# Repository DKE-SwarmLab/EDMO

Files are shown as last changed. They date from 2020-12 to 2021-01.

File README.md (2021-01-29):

# EDMO
Repository for EDucational MOdular Robots (EDMO)

EDMO is a custom-made EDucational MOdular robotic platform developed for robotics education at Maastricht University. The EDMO platform is designed as a versatile, modular robotic platform that allows students to construct and explore a variety of robotic morphologies including snake, biped, and quadruped configurations.

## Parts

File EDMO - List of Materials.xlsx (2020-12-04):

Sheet: EDMO BOX
List of Materials - EDMO BOX For EDMO Version 1.0 and 1.1
Table 1: Material costs (upper limits) for one EDMO box and components
Component | Amount | Costs[€]*
EDMO 1.0 robot module
3D-printed body parts and fasteners | 1 | 4.50
TurnigyTM TGY-50090M servo motor | 1 | 5.50
EDMO 1.1 robot module
3D-printed body parts and fasteners | 1 | 4.50
TrackStarTM TS-411MG servo motor | 1 | 15.60
EDMO DC motor module
3D-printed body parts | 1 | 3.00
RS PRO 6V brushed DC geared motor | 1 | 15.20
Amphenol Piher N15TS-103A3030 rotary encoder | 1 | 2.40
Electronics
Adafruit Feather M0 Proto board | 1 | 18.00
Adafruit Feather servo wing | 1 | 9.00
L298N DC motor driver board | 1 | 5.00
5V DC - 2A Raspberry Pi power converter | 1 | 6.80
Breadboard (53x82)mm | 1 | 5.00
10 kΩ metal film resistor (for LED) | 2 | 0.60
68 Ω metal film resistor | 3 | 1.20
RG-LED | 1 | 0.40
Proto cables male-male | 5 | 3.60
Proto cables female-male | 3 | 3.60
2-Position Switch | 1 | 0.90
USB-A to µUSB Cable | 1 | 4.90
Servo extension cables (60cm)(optional) | 3 | 3.70
Various
Plastic box/organizer | 1 | 20.00
Screwdriver, Flat, 2.5mm Tip | 1 | 4.00
Total costs of box with 2x EDMO 1.0 robot modules |  | <125
Total costs of box with 2x EDMO 1.1 robot modules |  | <145
*Costs per smallest available purchasing or production unit

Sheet: EDMO 1.0
List of Components - EDMO 1.0 -
Table 2: Parts of one EDMO robot version 1.0
Component | Amount
EDMO 1.0 body (PLA) | 1
EDMO 1.0 cover (PLA) | 1
EDMO 1.0 arm (PLA) | 1
TurnigyTM TGY-50090M servo motor | 1
Screw DIN 912 - M3x20mm | 1
Screw DIN 912 - M2x20mm | 1
Nut DIN 985 - M3 | 3
Washer DIN 125 - 3.2x7 | 4
Spirol threaded inserts M2x4mm | 2

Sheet: EDMO 1.1
List of Components - EDMO 1.1 -
Table 3: Parts of one EDMO robot version 1.1
Component | Amount
EDMO 1.1 body (PLA) | 1
EDMO 1.1 cover (PLA) | 1
EDMO 1.1 arm (PLA) | 1
TrackStarTM TS-411MG servo motor | 1
Screw DIN 912 - M3x16mm | 1
Screw DIN 912 - M2x20mm | 4
Nut DIN 985 - M3 | 6
Nut DIN 934 - M3 | 1
Washer DIN 125 - 3.2x7 | 2

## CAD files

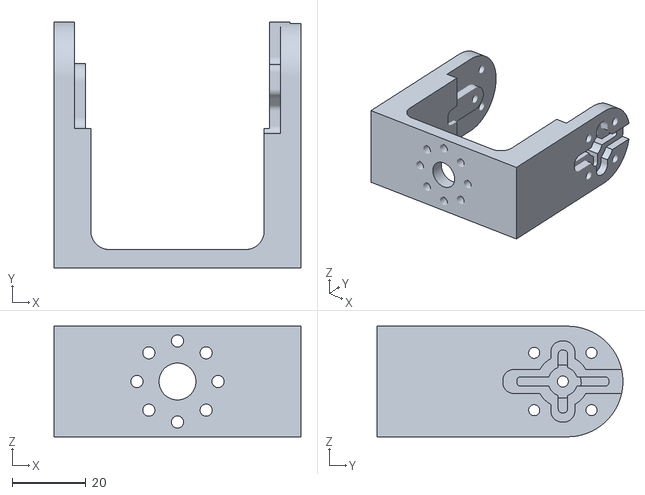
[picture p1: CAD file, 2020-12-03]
EDMO_V1-0/EDMOV1-0 STL/EDMO1-0_Arm.stl
67.0 x 66.7 x 30.0

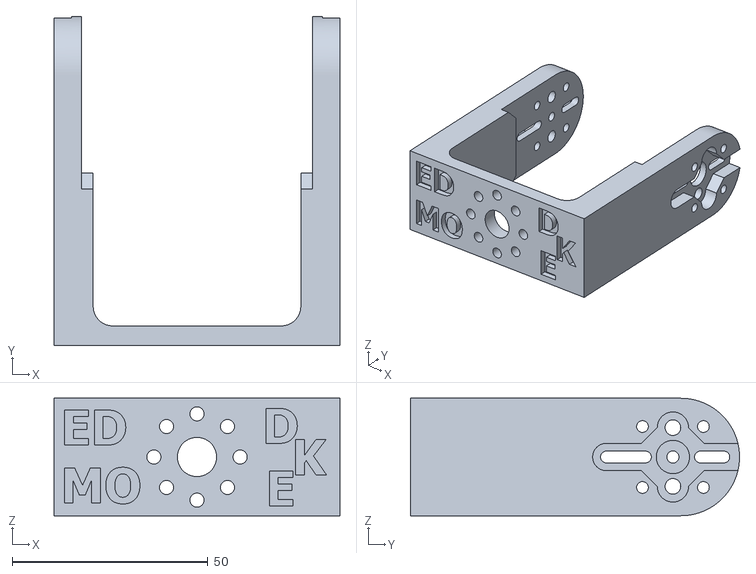
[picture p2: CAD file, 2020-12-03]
EDMO_V1-1/EDMO V1-1 STL/EDMO1-1_Arm.stl
73.0 x 84.0 x 30.0

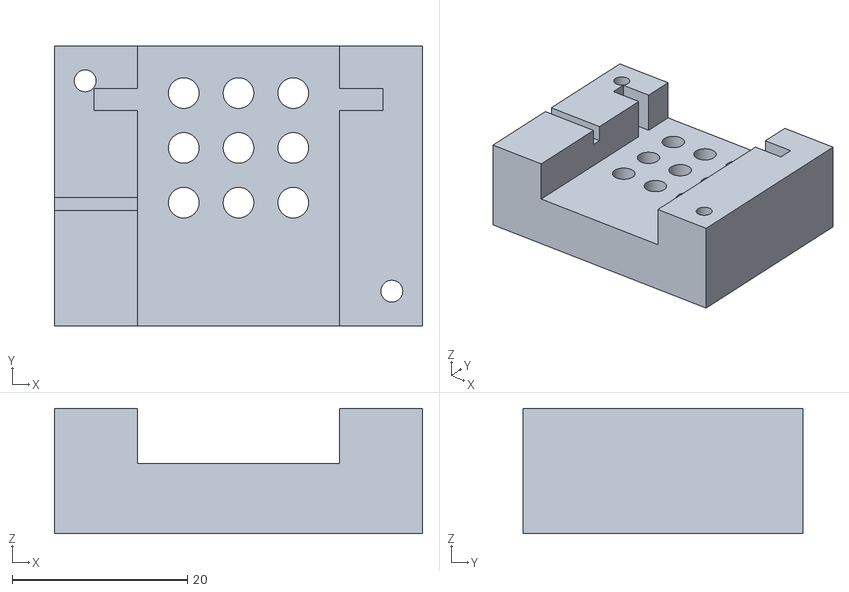
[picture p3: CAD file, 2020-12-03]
EDMO_V1-0/EDMOV1-0 STL/EDMO1-0_Cover.stl
42.0 x 32.0 x 14.3

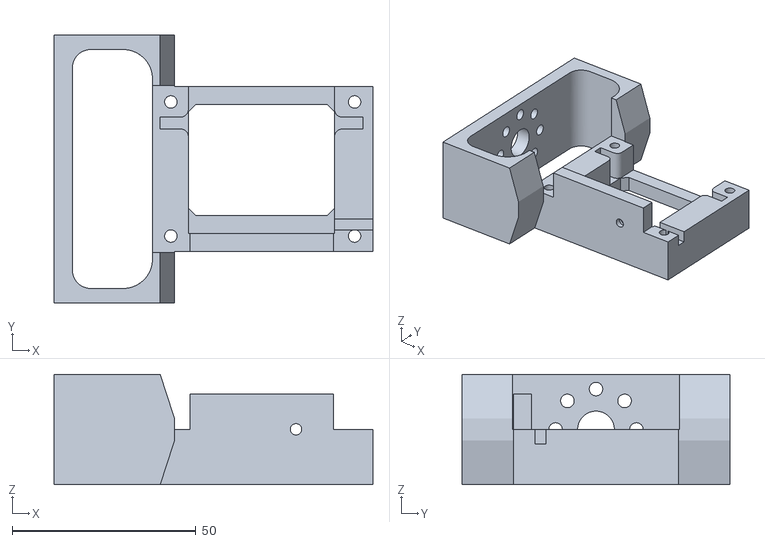
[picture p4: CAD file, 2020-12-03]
EDMO_V1-1/EDMO V1-1 STL/EDMO1-1_Body.stl
86.8 x 73.0 x 30.0

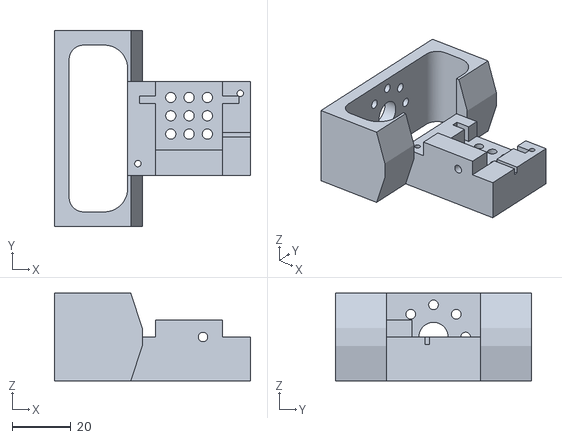
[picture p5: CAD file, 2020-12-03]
EDMO_V1-0/EDMOV1-0 STL/EDMO1-0_Body.stl
67.0 x 67.0 x 30.0

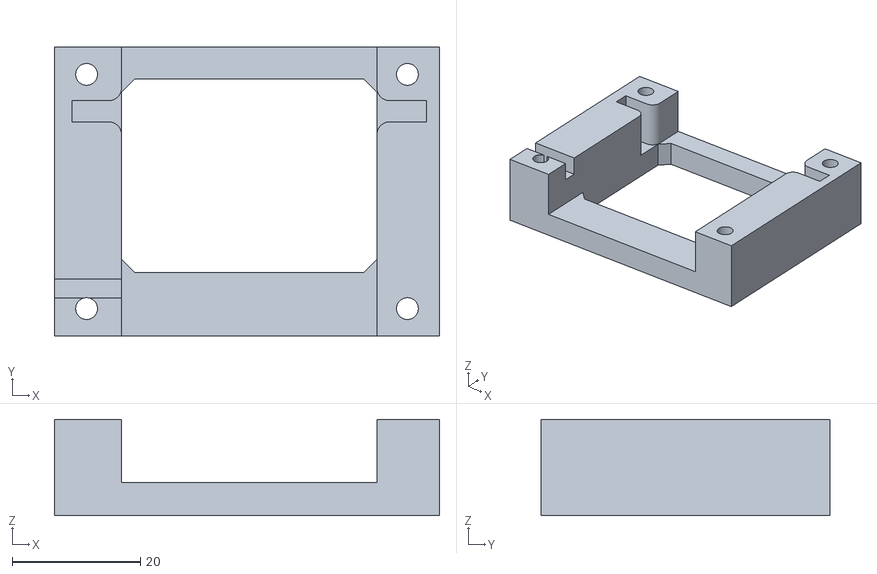
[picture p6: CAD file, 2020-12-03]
EDMO_V1-1/EDMO V1-1 STL/EDMO1-1_Cover.stl
60.0 x 45.0 x 15.0

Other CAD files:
EDMO_V1-0/EDMOV1-0 Inventor/EDMO_Module_TGY_50090M.iam
EDMO_V1-0/EDMOV1-0 Inventor/Workspace/DIN 125 - A 3,2.ipt
EDMO_V1-0/EDMOV1-0 Inventor/Workspace/DIN 912 - M2 x 0,4 x 20 x 19.ipt
EDMO_V1-0/EDMOV1-0 Inventor/Workspace/DIN 912 - M3 x 0,5 x 20 x 18,75.ipt
EDMO_V1-0/EDMOV1-0 Inventor/Workspace/DIN 985 - M3.ipt
EDMO_V1-0/EDMOV1-0 Inventor/Workspace/EDMO1-0_Arm.ipt
EDMO_V1-0/EDMOV1-0 Inventor/Workspace/EDMO1-0_Body.ipt
EDMO_V1-0/EDMOV1-0 Inventor/Workspace/EDMO1-0_Cover.ipt
EDMO_V1-0/EDMOV1-0 Inventor/Workspace/Servo_Horn_Cross_TGY.ipt
EDMO_V1-0/EDMOV1-0 Inventor/Workspace/Turnigy TGY-50090M Analog Servo.ipt
EDMO_V1-0/EDMOV1-0 Inventor/Workspace/spirol_pn_151048.ipt
EDMO_V1-1/EDMOV1-1 Inventor/EDMO1-1_Arm.ipt
EDMO_V1-1/EDMOV1-1 Inventor/EDMO1-1_Body.ipt
EDMO_V1-1/EDMOV1-1 Inventor/EDMO1-1_Cover.ipt
EDMO_V1-1/EDMOV1-1 Inventor/EDMO_TrackStar_TS_411MG.iam
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

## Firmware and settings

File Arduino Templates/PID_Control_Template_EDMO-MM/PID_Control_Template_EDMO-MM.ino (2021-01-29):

//EDMO-Motor Module - PID Control Template
//Author: DKE-SwarmLab
//This script contains a template for the implementation of a PID controller with the EDMO-Motor Module and the L298N DC motor driver board.
//The template provides a framework for the implementation of the PID controller and the operation of the DC motor driver board L298N.
//Furthermore it provides a function to read the PID-gains kp, ki, and kd via the serial monitor. Those need to be entered in the format <kp-value>,<ki-value>,<kd-value>

// *********************************************************************************************************************** //
// Variables                                                                                                               //
// *********************************************************************************************************************** //

//pin definition
#define ENA 9 //Arduino pin connected to the enable pin of the motor driver (for setting the motor speed via PWM)
#define IN1 21 //Arduino pin connected to the In1-pin of the DC motor driver board L298N(for setting the motor direction)
#define IN2 20 //Arduino pin connected to the In2-pin of the DC motor driver board L298N(for setting the motor direction)
#define SENSOR_PIN A0 //Analog input pin of the rotary encoder

// ******** <TODO> **********************
// ******** define interval between recomputing error and adjusting feedback (in milliseconds) ********************** 
const int INTERVAL = 0; 
unsigned long previousTime = 0;

int motorSpeed = 0; // speed of the motor, values between 0 and 255
int target = 512; // position (as read by potentiometer) to move the motor to, default value 512

// ******** <TODO> **********************
// ******** define the different gains **********************
float kp = 0.0; // proportional gain
float ki = 0.0; // integral gain
float kd = 0.0; // derivative gain

int pos = 0; // current position for plotting
//serial communication variables
float PID_values[4];
byte i = 0;
char record[100];
char recvchar;
byte indx = 0;

// setup code, setting pin modes and initialising the serial connection
void setup() 
{
    Serial.begin(115200);

    pinMode(ENA, OUTPUT);
    pinMode(IN1, OUTPUT);
    pinMode(IN2, OUTPUT);    
    pinMode(SENSOR_PIN, INPUT);   
}

void loop() 
{
        //  ******** <TODO> **********************
        //  ******** implement your code  here **********************

        //print actual motor position and target value to serial-monitor/plotter
        Serial.print(pos);
        Serial.print(" ");   
        Serial.println(target);
    
}

// method to set direction and speed of the motor
void setMovement(int dir, int speed1) 
{
        //  ******** <TODO> **********************
        //  ******** implement your code  here **********************
}
// *********************************************************************************************************************** //
// method for receiving commands over the serial port
void readInput() 
{
      if (Serial.available())
    {
        recvchar = Serial.read();
        if (recvchar != '\n')
        { 
            record[indx++] = recvchar;
        }
        else if (recvchar == '\n')
        {
          record[indx] = '\0';
          indx = 0;
          
          convertData(record);
          if(i==4){
          target = PID_values[0];
          kp = PID_values[1];
          ki = PID_values[2];
          kd = PID_values[3];
          Serial.print("Entered Values:");
          printData(PID_values);
          }
          else
          {
          Serial.println("Enter correct number of values separated by commas!!");            
          }
        }
    }
}
// *********************************************************************************************************************** //
//method for reading/interpreting serial input 
void convertData(char record[])
{
    i = 0;
    char *index = strtok(record, ",");
    while(index != NULL)
    {
       PID_values[i++] = atof(index); 
        index = strtok(NULL, ",");
    }
}
// *********************************************************************************************************************** //
//method for printing values entered via the serial monitor
void printData(float data[])
{
    for (byte j = 0 ; j < 4 ; j++)
    {
      Serial.print(data[j]);
      Serial.print('\t');
    }
    Serial.println(); 
}
